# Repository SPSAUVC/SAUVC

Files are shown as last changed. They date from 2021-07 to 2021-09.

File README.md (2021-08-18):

# Underwater vehicle project
4ed0a388-94ec-4229-88fc-241d18f35cce
Created on: 28 June 2021 by Eugene Ow.

Contributed by:

20/21 Semester 1 seniors (Eugene, Terrence, Brandon, Edthan)

20/21 Semester 2 seniors (Add your name here)
.
.
.

## Description:
This GitHub repository is created for our juniors, to allow them to access work from their seniors and to cultivate a culture within SAUVC to always think and plan ahead. 

By the way if you've seen us label anything as "CBot" or "RCBot" do note that they are actually meaning "AUV" and "HUV":

CBot (Competition robot) = AUV (Autonomous underwater vehicle)

RCBot (Research & competition robot) = HUV (Hybrid underwater vehicle)
 
## Others (Reports, Presentation slides, Videos, etc.):
Since GitHub only allows up to a maximum of 25MB, we can't really include most of our stuff like the 2 videos and the word document, but do head down to this link to view and edit them.

https://drive.google.com/drive/folders/1MYFr3oYZFT8594FtYBQqcVCKXcDlUzxP?usp=sharing![4ed0a388-94ec-4229-88fc-241d18f35cce](https://user-

## Lost files:
Hey no worries, if you can't find the files. You should have probably established a messaging group with your seniors by now, if you can't find anything on MSTeams and on here, just ask them. If they don't have it as well, there's a very good chance you'll have to do it out youself.

## Duplicate files:
Incase we've included anything that is duplicated (In GitHub), you should probably use the one in the ".zip" files because those are from MSTeams.

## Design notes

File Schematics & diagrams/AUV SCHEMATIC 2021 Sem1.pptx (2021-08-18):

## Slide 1

Webcam

Logitech HD webcam C525

USB Connection

Wireless Keyboard & Mouse

USB

Portable Charger

Type C USB Cable

Ball Dropper

USB

USB Hub

XSENS MTI-300-2A8G4

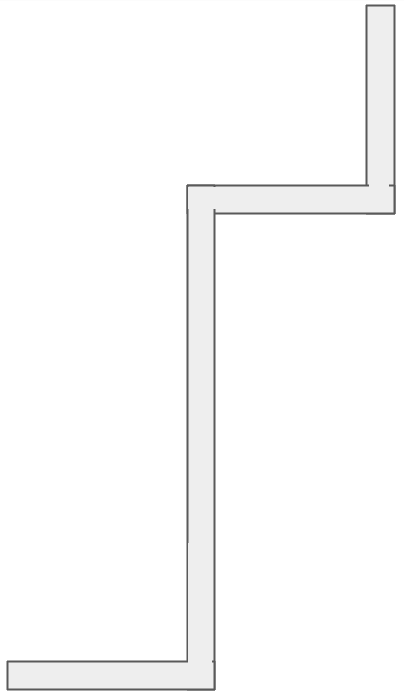
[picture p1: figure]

USB Connection

Ethernet Cable

USB Connection

Raspberry Pi 4

USB Connection

Arduino
MEGA

USB Connection

Interface
Board

I2C Level Convertor

RPi.Screen

Kill
Switch

Ball
Dropper

Kill
Switch

Schematic Diagram

Ribbon Cable

Raspberry Pi
Display

Mounted on top

Sonar BLUART

11.1V Lipo

Depth Sensor
BAR30

0V

S1

RPI.SBTOOTH

ARD.SBTOOTH

0V

S1

SONAR

Sabertooth
V2.00

Sabertooth
V2.00

ZOLTA
LiPo Batteries
11.1V
3S

Thruster

Thruster

Thruster

M1A

M1B

B+

B-

M2A

M2B

Thruster

KeyBoard

Mouse

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
## Schematic Diagram

Old Schematic from 2020 Sem 2

KeyBoard

Portable Charger

Micro USB Cable

Mouse

SONAR

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
BLUSART (USB to TTL)

Serial Port = /dev/ttyUSB3

Serial Port = /dev/ttyUSB1

Wireless Keyboard & Mouse

Logitech HD webcam C525

XSENS MTI-300-2A8G4

Serial Port = /dev/ttyUSB4

Raspberry Pi 4

KillSwitch

Serial Port = /dev/ttyUSB2

GND

Webcam

GPIO 24

GND

GPIO
14

GPIO 23

Serial Port = /dev/ttyUSB0

Arduino
MEGA

330R

52

SDA
(A4)

GND

5V

SDA

SCL

GND

5V

I2C Level Convertor

10kR

0V

5V

11

GND

SCL
(A5)

Sabertooth
V2.00

0V

S1

ZOLTA
LiPo Batteries
11.1V
3S

S1

Depth Sensor
BAR30

Sabertooth
V2.00

BallDropperPCB

TIP120

820R

Solenoid

1N4007

12V

Thruster

M1A

M1B

B+

B-

M2A

M2B

Thruster

Thruster

M1A

M1B

B+

B-

M2A

M2B

Thruster

+

+

+

+

+

Linear Actuator

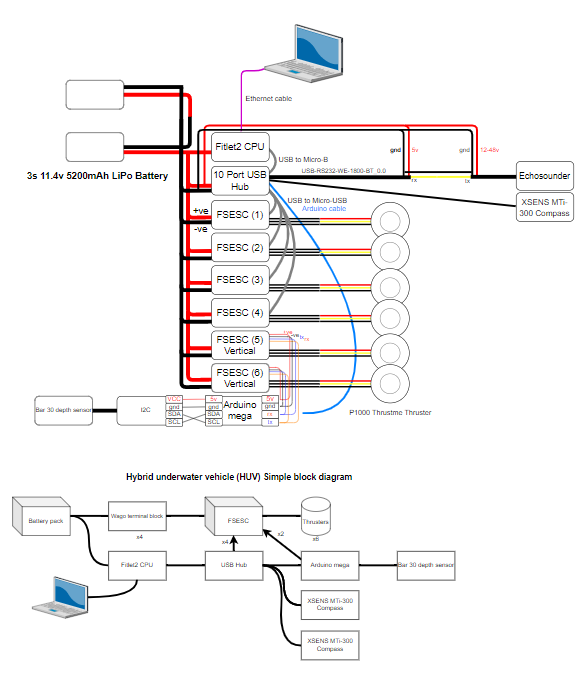
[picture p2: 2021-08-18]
Schematics & diagrams/HUV Schematics.png

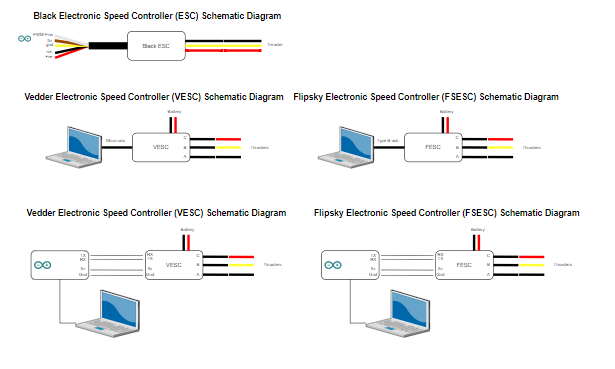
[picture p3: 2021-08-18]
Schematics & diagrams/Connections for HUV.png

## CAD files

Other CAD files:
Camera/Camera No.1/FrontCameraHolderV4.ipt
Camera/Camera No.2/bottomcameraholder_6_24_2021.ipt
Echo Sounder/ECHO SOUNDER HOLDER FINAL DESIGN (revised).ipt

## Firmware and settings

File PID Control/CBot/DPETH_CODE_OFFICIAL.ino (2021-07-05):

#include <TimerOne.h>// Library same as TimerOne, not neeon
#include <Wire.h> // library to allow for I2C and/or TWI communiation to devices
#include "MS5837.h" //library to configure depth sensor
MS5837 sensor; //setting depth sensor as variable sensor
#include <SoftwareSerial.h> // library for serial communications
#include <SabertoothSimplified.h> // library to send commands to sabertooth to run thrusters
#define setvalue 127; // speed for downwards motion
//SoftwareSerial SWSerial(NOT_A_PIN,11); // sabertooth Rx serial recieve pin
SabertoothSimplified ST(Serial1);  // setting up sabertooth
int DEPTH[3]; // DEPTH array to find median value for finer depth calculations
String D = "72"; // D used to control on off of depth code, D = 'H' will run the code
//String D1="0"; //ignore this for now
int Set_depth = 80; // our codes chosen depth
int MotorSpd1 = -40; // upwards motion motor speeds
int MotorSpd2 = setvalue; // downwards motion motor speed
double error = 0; //for error calculation and PID

double kp = 0.9; //0.8, proportional constant of PID calculations
double ki = 0.02; //0.02, intergral constant of PID calculations
double kd = 0.025; //0.025, derivative constant of PID calculations

double PErr_now = 0; // porpotional error calculation variable and error at the time
double DErr = 0; // derivative error calculation variable

unsigned long lastTime;
double PErr_last = 0; // porpotional error of last 1 sec compared to porptional error now
double IntErr = 0; // intergral error calculation variable
double M = 0; // motor speed control needed to correct error

void setup() {
  Serial.begin(9600); //initialzie serial for arduino
  Wire.begin(); // initialize I2C
  sensor.init(); // initalize dpeth sensor
  sensor.setModel(MS5837::MS5837_30BA); //changed 02BA to 30BA, changing to our new depth sensor
  sensor.setFluidDensity(997); // sensor fluid density sensing setting
  Serial1.begin(9600); // initiate our sabertooth serial
  Timer1.initialize(50000);//100000 from 10000(microseconds), to run GODOWN code after every 0.1secs1
  Timer1.attachInterrupt(GODOWN);// interrupt to create sub-loop
}

void loop() {
  if (Serial.available() != 0) { // checking for serial
    D = Serial.read(); //reading for '72' to come in from RPI
  }
  //This part is to calculate median depth so we can better accurately determine
  //how off our depth is
  int done = 1;
  int x;
  sensor.read();//depths sensor reads in meters
  DEPTH[0] = sensor.depth() * 100; //eg. 0.15 x 100 = 15, this changes it to cm
  sensor.read();
  DEPTH[1] = sensor.depth() * 100;
  sensor.read();
  DEPTH[2] = sensor.depth() * 100;
  //this part still figuring out, will list in journal once ik
  while (done != 0) {
    for (int j = 0; j < 2; j++) {
      if (DEPTH[j] > DEPTH[j + 1]) {
        x = DEPTH[j + 1];
        DEPTH[j + 1] = DEPTH[j];
        DEPTH[j] = x;
        done = 1;
      }
      else done = 0;
    }
  }
  if (DEPTH[1] < 0) {
    DEPTH[1] = 0;
  }
  Serial.println(M);// Motor change need, found in GODOWN
  Serial.println(error);// error from set_depth, found in GODOWN
  Serial.print("DEPTH=");
  Serial.println(DEPTH[1]);// current depth
  Serial.print("PErrMS2=");
  Serial.println(MotorSpd2);// current speed
  Serial.println("\n");
  //delay(1000);// delay to print out properly in serial monitor for reading
}

void GODOWN() {
  if (D == "72") {
    //Set-depth = 60,
    error = double(Set_depth) - double(DEPTH[1]); // error calculation
    PErr_now = (error / 200) * 100; // porpotional error calculation in percentage
    //this part still confuses me, will keep working to understand
    if (PErr_now > 10) { //before reaching 10cm error gap
      MotorSpd2 = setvalue;
      ST.motor(1, MotorSpd2); //127
      ST.motor(2, MotorSpd2); //127
      Serial.println("Going down to set depth");
    }
    if (PErr_now < 0) { //if passes desired value(conv)
      ST.motor(1, 0); //0
      ST.motor(2, 0); //0
      Serial.println("To far past depth");

    }
    if (PErr_now < 2 && PErr_now >= 0) { //if 1cm error gap, reset Integral
      IntErr = 0;
      PErr_last = 0;
      MotorSpd2 = setvalue;
      ST.motor(1, 90);
      ST.motor(2, 90);
      Serial.println("Perfect depth");
    }
    if ((PErr_now >= 2) && (PErr_now <= 10)) { //error gap inbtw 1cm and 20cm
      Serial.println("Running PID");
      DErr = PErr_now - PErr_last;
      IntErr += PErr_now;

      M = (kp * PErr_now + ki * IntErr + kd * DErr);

      if (M > 100)
        M = 100;
      if (M < 0) //clip M to 0 if M=-ve
        M = 0;
      PErr_last = PErr_now;
      if (M > 0) {
        if (MotorSpd2 > 0){
        MotorSpd2 = int(MotorSpd2 * (1.0 - M / 100.0));
        ST.motor(1, MotorSpd2);
        ST.motor(2, MotorSpd2);
      }
      else if(MotorSpd2 == 0){
        MotorSpd2 = 25;
        ST.motor(1, MotorSpd2);
        ST.motor(2, MotorSpd2);
      }
      }
      else if (M < 0) {
        // MotorSpd1=int(MotorSpd1*(1.0-M/100.0));wrong
        ST.motor(1, 0); //0
        ST.motor(2, 0); //0
      }
    }
  }
  if (D == "76") {
    ST.motor(1, 0);
    ST.motor(2, 0);
  }
}

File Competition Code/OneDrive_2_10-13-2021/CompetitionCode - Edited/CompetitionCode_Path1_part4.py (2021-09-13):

#This code has not been verified but I tried my best to get
#the best product I could while working at home. Do make sure
#to test this code at the pool.

#This code essentially does this few things:
#
# 1) Check gate position relative to vehicle
# 2) Position vehicle correctly while double checking
# 3) Move forward to enter gate
# 4) Stop vehicle
# 5) Import next code

import numpy as np
import cv2
import time
import serial
from ctypes import *
from pysabertooth import Sabertooth
from brping import PingID 

object_detector = cv2.createBackgroundSubtractorMOG2(history = 100, varThreshold = 40)

webcam = cv2.VideoCapture(0) #Open camera, use either '-1', '0' or '1'

Set = 0
error = 0

desire_angle_addition_int = 0 
desire_angle_addition_Bool = True

Kp =7
Ki=0.2
Kd=0.25

value = 0
value1 = 0
value2 = 0
value3 = 0
value4 = 0

SpeedNowL = 65
SpeedNowR = 65

i = 0
ser = serial.Serial("/dev/ttyUSB0",9600)

myPing = pingID()
myPing.connect_serial("/dev/ttyUSB1", 9600)

saber=Sabertooth('/dev/ttyS0',baudrate=9600,address=128,timeout=0.1)

gate_right = False
gate_left = False

#You won't be viewing anything during competition, but this isn't for you.
width = 640
height = 640
dim = (width, height)

#Checks for a ping, to make sure sonar is working
if myPing.initialize() is False:
    print("Failed to initialize ping")

def sonar():
    data = myPing.get_distance_simple() #Gets simple distance data, including distance
    Dist = data["distance"]/10 #Converts distance data from mm to cm
    return Dist

def get_angle(ser):
    global value
    ser.reset_input_buffer()
    mydata=[]
    while True:
        count=0
        done =1
        while done !=0:
            for count in range(0,20):
                data = ser.read()
                data=hex(ord(data)) 
                data=int(data,16)
                mydata.append(data)
            count=0
            done=0
                
        if (mydata[0]==0xfa) and (mydata[1] ==0xff):

            data1=mydata[7]<<24
            data2=mydata[8]<<16
            data3=mydata[9]<<8
            data4=mydata[10]
            data5=mydata[11]<<24
            data6=mydata[12]<<16
            data7=mydata[13]<<8
            data8=mydata[14]
            data9=mydata[15]<<24
            data10=mydata[16]<<16
            data11=mydata[17]<<8
            data12=mydata[18]
         
            x = data1 + data2 + data3 + data4
            y= data5 + data6 + data7 + data8
            z = data9 + data10 + data11 + data12
                
            cp= pointer(c_int(z)) 
            fp=cast(cp,POINTER(c_float))
            value = fp.contents.value
           
        if (-180<value) and (value<180):
            return value

        
def calculate_error_new(ang_set, ang_now, error, value1, value2, value3, value4):
    if ang_set == ang_now:
        error = 0
    elif ang_set > ang_now:
        value3 = 360- ang_set +ang_now
        value4 = ang_set - ang_now
        
        if value4 > value3:
            error = value3
        elif value4 < value3:
            error = value4
        elif  value4 == value3:
            error = value4
            
    elif ang_set < ang_now:
        value1 = 360 - ang_now +ang_set
        value2 = ang_now - ang_set
        
        if value1 > value2:
            error = value2
        elif value1< value2:
            error = value1
        elif value1 == value2:
            error = value1
            
    return error, value1, value2, value3, value4


#Function to run PID calculation. Using error calculated and set kp,ki,kd constants,
#this code will run and calculate the variable M_t which will be used
#to calculate the change in speed needed for the motors to help our bot turn left or right
#to fix our error and return it back on track moving forwards in the direction of our set angle. 
def pid(error, kp, ki, kd):
    
    global PErr_last
    global IntErr
    
    M_t =0
    PErr_now = (error/360) *100# calculation to get our proportional error
    DErr = PErr_now - PErr_last# calculation to get our differential error
    IntErr += PErr_now# calculation to get our inegral error

    M_t = ( kp * PErr_now + ki * IntErr + kd * DErr) # calculation to get our percentage change in speed needed to fix error
    
    # if statement to cap our percentage change at 100%
    if M_t>100:
        M_t=100
    if M_t<-100:
        M_t=-100
    
    PErr_last= PErr_now
    
    return abs(M_t)

#Functions to drive AUV in respective direction
def FORWARD(m1, m2):
    saber.drive(2,-m1)
    saber.drive(1,-m2)
    
    print("m1:",m1)
    print("m2:",m2)
    print("Moving forward\n")
    print("=================")
    
    
def RIGHT_TURN(m1, m2,M):
    new_m1=int(m1*(1.0-(M/100.0)))
    saber.drive(2,-new_m1)
    saber.drive(1,-m2)
    
    print("m1:",new_m1)
    print("m2:",m2)
    print("Turning right")
    print("=================")

def LEFT_TURN(m1,m2,M):
    new_m2=int(m2*(1.0-(M/100.0)))
    saber.drive(2,-m1)
    saber.drive(1,-new_m2)
    
    print("m1:",m1)
    print("m2:",new_m2)
    print("Turning left")
    print("=================")
               
def stop():
    saber.drive(1,0)
    saber.drive(2,0)
    
    print("m1: 0")
    print("m2: 0")
    print("Stopping\n")
    
    f = open("state.txt", "w")
    f.write("2")
    f.close()
   
PErr_last = 0 
IntErr = 0
M=0   
desire_angle_addition_Bool = False
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

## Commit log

2021-06-28 Create Arduino
2021-06-28 Arduino files
2021-07-02 Mounting board (RCBot)
2021-07-04 Echo Sounder CAD File
2021-07-04 Black ESC
    Due to the nature of the "black" ESC being used for remote controlled toys, it requires a kick-start to get it working properly. I found that in order to do that you have to engage the throttle stick (Which we didn't have) to the bottom position. If you would like to read more into what happen when I played with the "black" ESC please read Eugene's Journal from Week 3 - 4.
2021-07-04 Update Black ESC
2021-07-04 VESC Tool
2021-07-04 Black ESC
2021-07-04 Camera No.1
2021-07-04 Bucket detection
2021-07-05 ECHO SOUNDER HOLDER FINAL DESIGN (revised)
    [ECHO SOUNDER HOLDER FINAL DESIGN (revised).ipt]
2021-07-05 RCBot mounting board
    [Brackets RC mounting board.ipt, RCBOT BTM TIER (FLIPSKY).ipt, RCBOT board TOP TIER (FLIPSKY).ipt]
2021-07-05 Thrusters wire holder
2021-07-05 PID Control
2021-08-18 Schematics & diagrams
2021-08-18 Interface board
2021-08-18 Battery holder
2021-08-18 Mounting board (AUV)
2021-08-18 Mounting board (HUV)
